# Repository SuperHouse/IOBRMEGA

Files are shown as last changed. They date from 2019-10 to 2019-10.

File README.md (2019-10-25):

I/O Breakout Shield (Mega)
==========================
Copyright 2017 SuperHouse Automation Pty Ltd  
SuperHouse site:  <www.superhouse.tv>  

Breaks out sets of I/O pins to 2x6 pin headers.

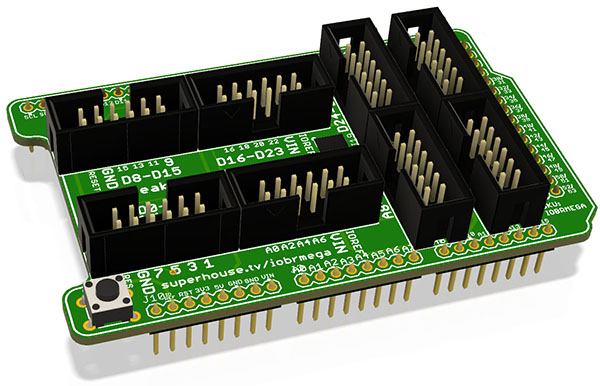
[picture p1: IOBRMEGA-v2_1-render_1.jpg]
PCB render


Features:

 * 8 x 2x6 shrouded pin headers
 * Each header provides 8 x data lines, GND, VIN, IOREF, and RESET

More information is available at:

  http://www.superhouse.tv/iobrmega

INSTALLATION
------------
The design is saved as an EAGLE project. EAGLE PCB design software is
available from www.cadsoftusa.com free for non-commercial use. To use
this project download it and place the directory containing these files
into the "eagle" directory on your computer. Then open EAGLE and
navigate to the project.

DISTRIBUTION
------------
The specific terms of distribution of this project are governed by the
license referenced below.

LICENSE
-------
Licensed under the TAPR Open Hardware License (www.tapr.org/OHL).
The "license" folder within this repository also contains a copy of
this license in plain text format.

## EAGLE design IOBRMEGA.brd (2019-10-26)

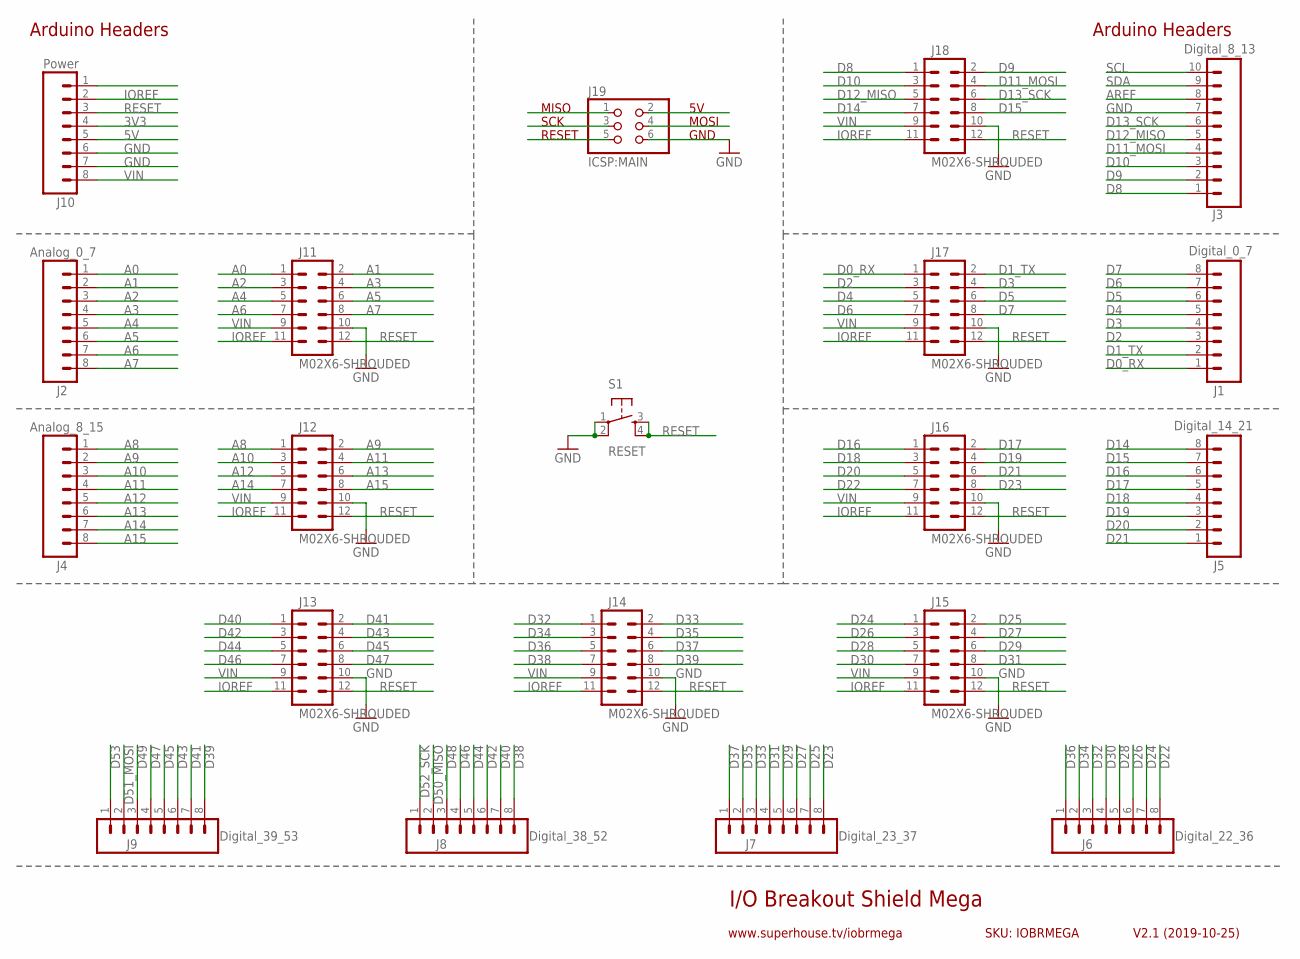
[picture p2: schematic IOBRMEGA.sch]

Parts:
J1: Digital_0_7; 1X08-P-BELOW
J2: Analog_0_7; 1X08-P-BELOW
J3: Digital_8_13; 1X10-P-BELOW
J4: Analog_8_15; 1X08-P-BELOW
J5: Digital_14_21; 1X08-P-BELOW
J6: Digital_22_36; 1X08-P-BELOW
J7: Digital_23_37; 1X08-P-BELOW
J8: Digital_38_52; 1X08-P-BELOW
J9: Digital_39_53; 1X08-P-BELOW
J10: Power; 1X08-P-BELOW
J11, J12, J13, J14, J15, J16, J17, J18: M02X6-SHROUDED; 2X06-SHROUDED
J19: ICSP:MAIN; 2X03
S1: RESET; TACTILE-PTH-6MM

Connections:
3V3: J10.4
5V: J10.5
A0: J2.1, J11.1
A1: J2.2, J11.2
A2: J2.3, J11.3
A3: J2.4, J11.4
A4: J2.5, J11.5
A5: J2.6, J11.6
A6: J2.7, J11.7
A7: J2.8, J11.8
A8: J4.1, J12.1
A9: J4.2, J12.2
A10: J4.3, J12.3
A11: J4.4, J12.4
A12: J4.5, J12.5
A13: J4.6, J12.6
A14: J4.7, J12.7
A15: J4.8, J12.8
AREF: J3.8
D0_RX: J1.1, J17.1
D1_TX: J1.2, J17.2
D2: J1.3, J17.3
D3: J1.4, J17.4
D4: J1.5, J17.5
D5: J1.6, J17.6
D6: J1.7, J17.7
D7: J1.8, J17.8
D8: J3.1, J18.1
D9: J3.2, J18.2
D10: J3.3, J18.3
D11_MOSI: J3.4, J18.4
D12_MISO: J3.5, J18.5
D13_SCK: J3.6, J18.6
D14: J5.8, J18.7
D15: J5.7, J18.8
D16: J5.6, J16.1
D17: J5.5, J16.2
D18: J5.4, J16.3
D19: J5.3, J16.4
D20: J5.2, J16.5
D21: J5.1, J16.6
D22: J6.8, J16.7
D23: J7.8, J16.8
D24: J6.7, J15.1
D25: J7.7, J15.2
D26: J6.6, J15.3
D27: J7.6, J15.4
D28: J6.5, J15.5
D29: J7.5, J15.6
D30: J6.4, J15.7
D31: J7.4, J15.8
D32: J6.3, J14.1
D33: J7.3, J14.2
D34: J6.2, J14.3
D35: J7.2, J14.4
D36: J6.1, J14.5
D37: J7.1, J14.6
D38: J8.8, J14.7
D39: J9.8, J14.8
D40: J8.7, J13.1
D41: J9.7, J13.2
D42: J8.6, J13.3
D43: J9.6, J13.4
D44: J8.5, J13.5
D45: J9.5, J13.6
D46: J8.4, J13.7
D47: J9.4, J13.8
D48: J8.3
D49: J9.3
D50_MISO: J8.2
D51_MOSI: J9.2
D52_SCK: J8.1
D53: J9.1
GND: J3.7, J10.6, J10.7, J11.10, J12.10, J13.10, J14.10, J15.10, J16.10, J17.10, J18.10, J19.6, S1.1, S1.2
IOREF: J10.2, J11.11, J12.11, J13.11, J14.11, J15.11, J16.11, J17.11, J18.11
RESET: J10.3, J11.12, J12.12, J13.12, J14.12, J15.12, J16.12, J17.12, J18.12, S1.3, S1.4
SCL: J3.10
SDA: J3.9
VIN: J10.8, J11.9, J12.9, J13.9, J14.9, J15.9, J16.9, J17.9, J18.9

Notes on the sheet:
I/O Breakout Shield Mega
V2.1 (2019-10-25)
www.superhouse.tv/iobrmega
SKU: IOBRMEGA
Arduino Headers
GND
MISO
RESET
SCK
MOSI

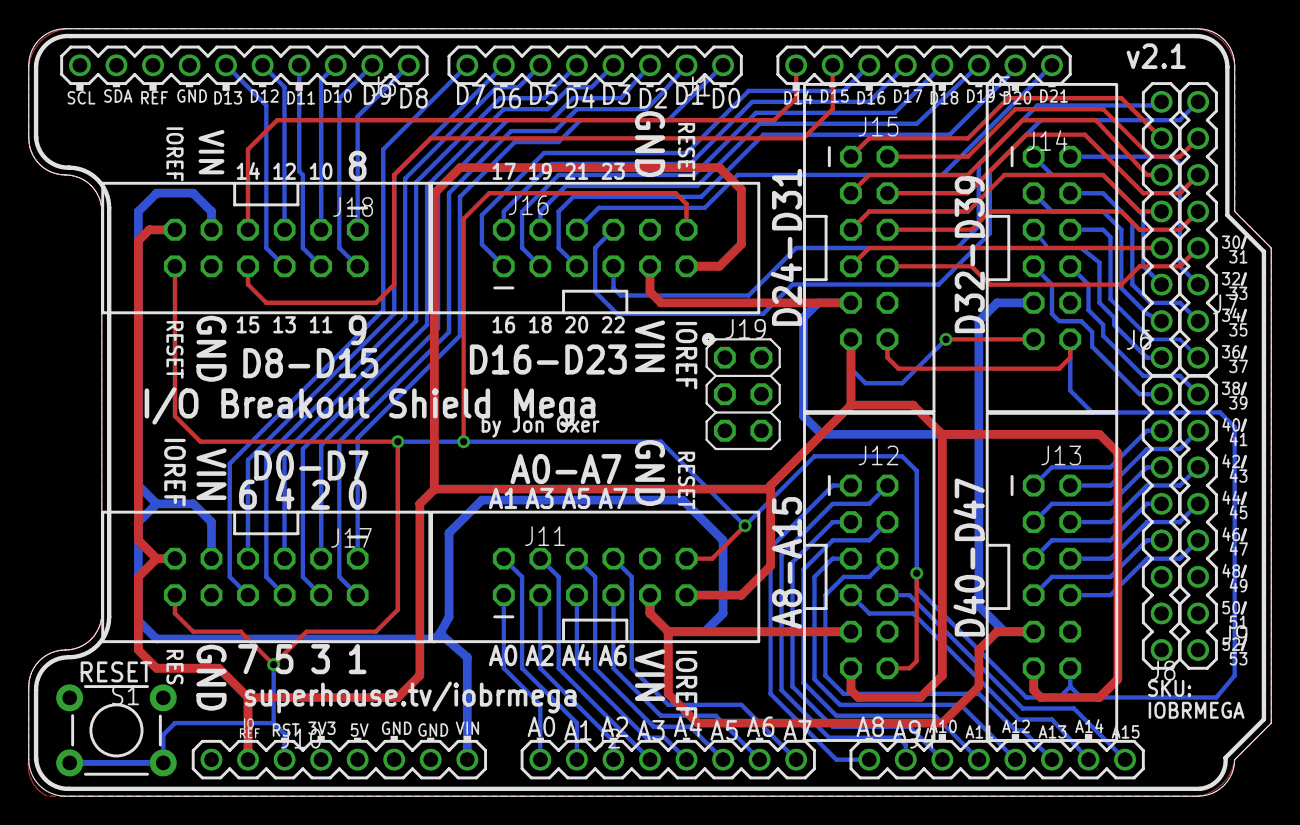
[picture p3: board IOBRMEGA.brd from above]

Board: 2 copper layers, 86.4 x 53.3 mm, 20 parts (0 on the bottom side), 68 nets.

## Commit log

2017-07-21 Initial project import
    [IOBRMEGA.brd, IOBRMEGA.sch]
2017-07-24 Expanded headers to 2x6 to include IOREF and RESET for v2.0 release
    [IOBRMEGA.brd, IOBRMEGA.sch]
2019-07-18 Part swap to SuperHouse library to add 3D models
    [IOBRMEGA.brd, IOBRMEGA.sch]
2019-10-25 Updated for v2.1 release
    [IOBRMEGA.brd, IOBRMEGA.sch]
2019-10-26 Final tweaks for v2.1 release
    [IOBRMEGA.brd, IOBRMEGA.sch]

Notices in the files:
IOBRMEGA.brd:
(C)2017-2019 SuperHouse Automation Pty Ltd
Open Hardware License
